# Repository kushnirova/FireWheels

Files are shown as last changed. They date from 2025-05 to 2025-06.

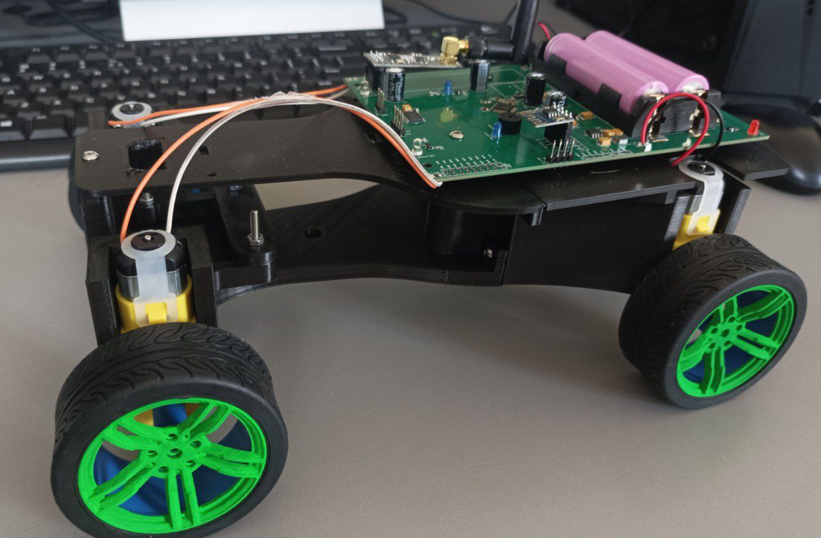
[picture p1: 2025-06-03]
photos/side2.jpg

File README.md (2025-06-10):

# 🏁 FireWheels 🏎️💨

**Projekt semestralny z przedmiotu Systemy Wbudowane i Mikroprocesory -** zdalnie sterowany robot mobilny do wyścigów i driftu

**Autorzy:** Daria Kushnirova i Mateusz Kowalczyk

**Data rozpoczęcia:** 01.05.2025

---

## ⚙️ Opis projektu

FireWheels to dynamiczny, czterokołowy robot mobilny, stworzony do szybkiej jazdy i kontrolowanych poślizgów. Napęd jest realizowany na każde z kół. Wykorzystuje układ kierowniczy Ackermanna napędzany serwomechanizmem. Komunikacja odbywa się bezprzewodowo przez Bluetooth, możliwe jest również sterowanie radiowe 2.4 GHz. Robot wyposażony jest w sygnalizacyjne diody LED oraz klakson/dodatkowy serwomechanizm. Sterowanie jest możliwe w dwóch trybach: za pomocą aplikacji mobilnej (Bluetooth) lub kontrolera bezprzewodowego (nRF). Robot został zaprogramowany za pomocą technologii FreeRTOS w STM32CubeIDE. Aplikacja mobilna napisana w Flutter (Dart) przy użyciu Android Studio.

---

## 📸 Multimedia

- **Zdjęcia:** Zobacz naszego FireWheels w akcji! [photos](https://github.com/kushnirova/FireWheels/tree/main/photos)
- **Wideo:** Nagrania z testów i prezentacji możliwości robota: [link zostanie dodany później]

---

## 🛠️ Użyte technologie i narzędzia

### Robot 🤖

- **Mikrokontroler:** STM32F103C8T6
- **IDE:** STM32CubeIDE
- **Język programowania:** C
- **Sterowanie silnikami:** Toshiba TB6612FNG x2
- **Serwomechanizm:** SG90
- **Komunikacja:** Moduł Bluetooth VG6328A/HC-04, moduł radiowy nRF24L01+PA+LNA 2.4 GHz
- **Zasilanie:** Akumulator Li-Ion 3.7V 18650 (2s)
- **Elementy dodatkowe:**
    - Diody LED
    - Buzzer / Dodatkowy serwomechanizm

### Aplikacja Mobilna 📱

- **Platforma:** Android & iOS
- **Język programowania:** Dart (Flutter)
- **Narzędzia:** Android Studio
- **Komunikacja:** Bluetooth

---

## 🛠️ Postęp prac

Postępy w poszczególnych obszarach projektu:

- **Projektowanie schematów:** [schematic_pcb](https://github.com/kushnirova/FireWheels/tree/main/schematic_pcb)
- **Projektowanie obudowy:** [3d_models](https://github.com/kushnirova/FireWheels/tree/main/3d_models)
- **Oprogramowanie robota i mikrokontrolera:** [firmware](https://github.com/kushnirova/FireWheels/tree/main/firmware/FireWheels)
- **Oprogramowanie aplikacji mobilnej:** [FireWheelsApp](https://github.com/kushnirova/FireWheels/tree/main/FireWheelsApp)

---

## 📝 Wnioski

[wnioski zostaną dopisane po ukończeniu projektu]

---

## 📧 Kontakt

Masz pytania? Skontaktuj się z nami:

- Email: [21267@student.ans-elblag.pl](mailto:21267@student.ans-elblag.pl) / [21244@student.ans-elblag.pl](mailto:21244@student.ans-elblag.pl)
- GitHub: https://github.com/kushnirova / https://github.com/kowmat

---

## 📜 Licencja

**Licencja:** MIT

---

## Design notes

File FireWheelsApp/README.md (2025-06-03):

# firewheelsapp

A new Flutter project.

## Getting Started

This project is a starting point for a Flutter application.

A few resources to get you started if this is your first Flutter project:

- [Lab: Write your first Flutter app](https://docs.flutter.dev/get-started/codelab)
- [Cookbook: Useful Flutter samples](https://docs.flutter.dev/cookbook)

For help getting started with Flutter development, view the
[online documentation](https://docs.flutter.dev/), which offers tutorials,
samples, guidance on mobile development, and a full API reference.

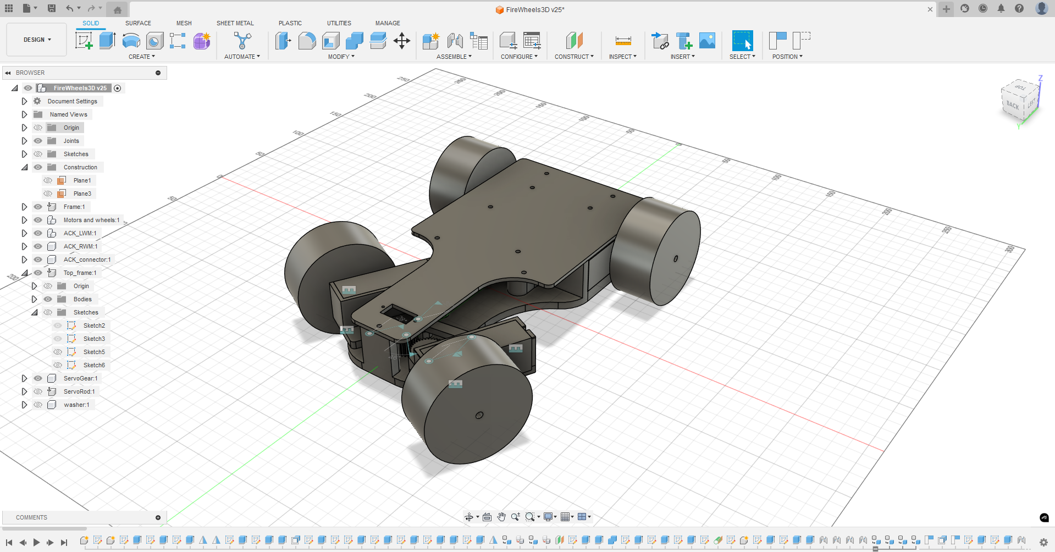
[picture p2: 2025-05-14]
3d_models/WIP_overview_1A.png

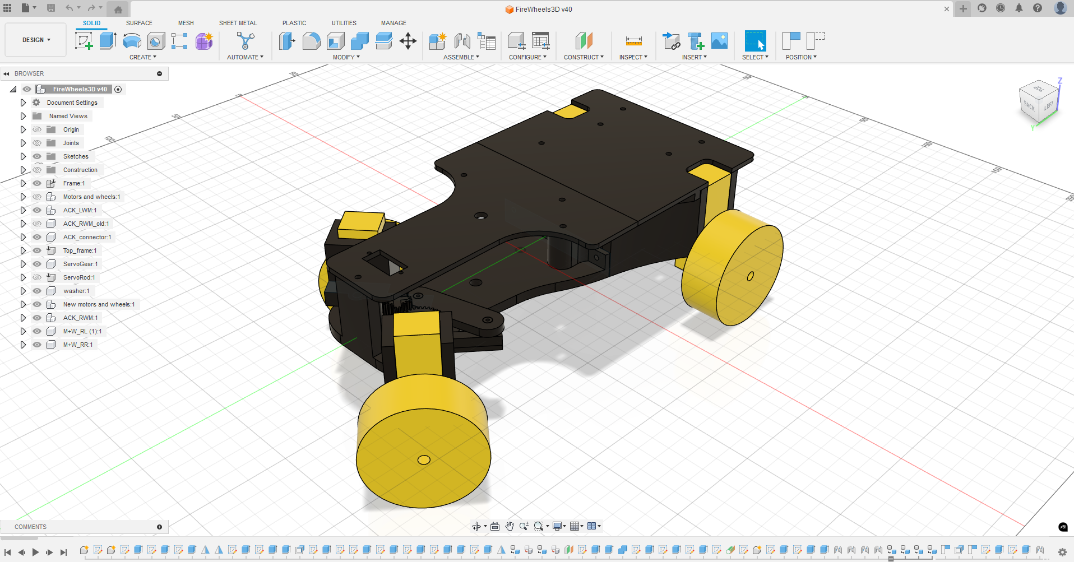
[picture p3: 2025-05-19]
3d_models/Final3D_overview_1B.png

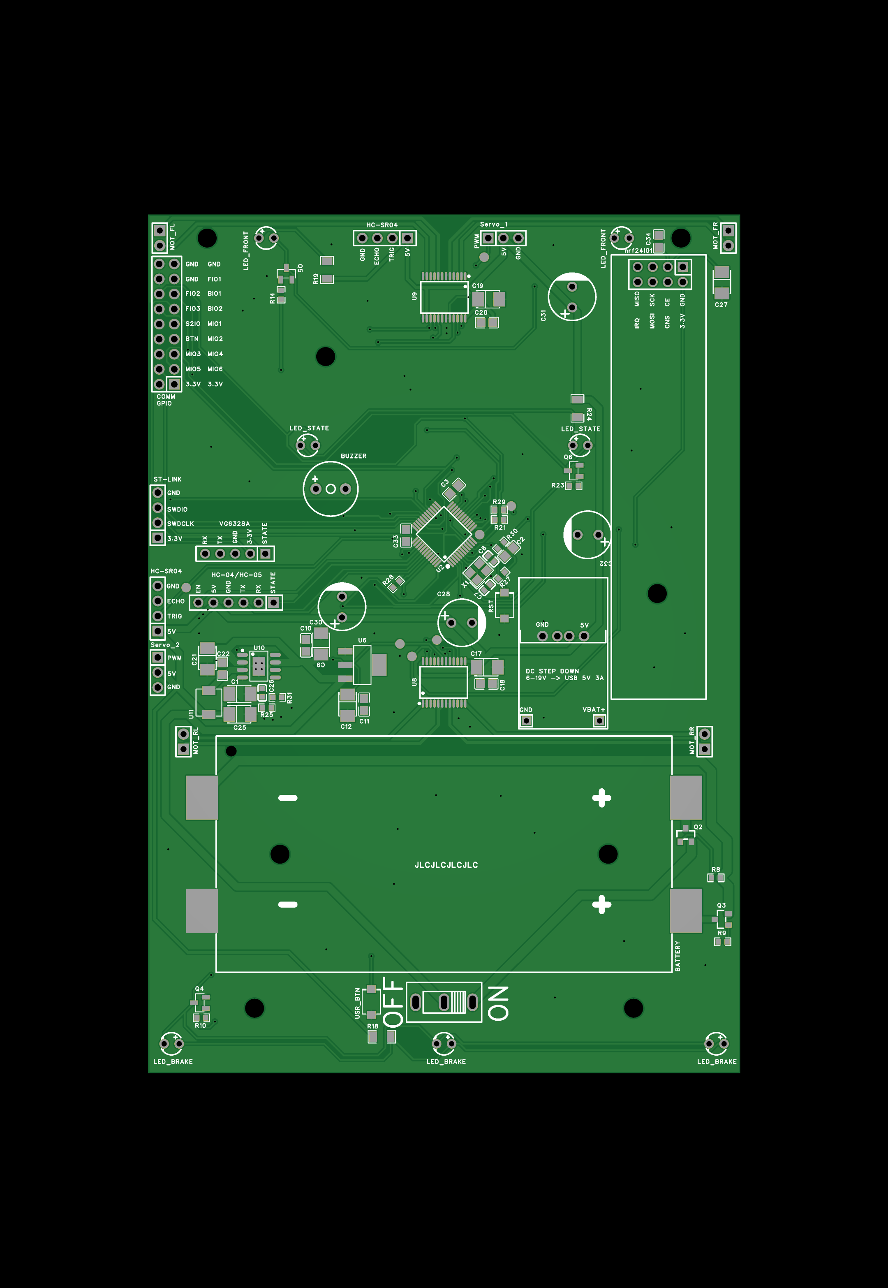
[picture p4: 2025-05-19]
schematic_pcb/PDF_PNG/PCB_MOTHERBOARD_SIDE_A.png

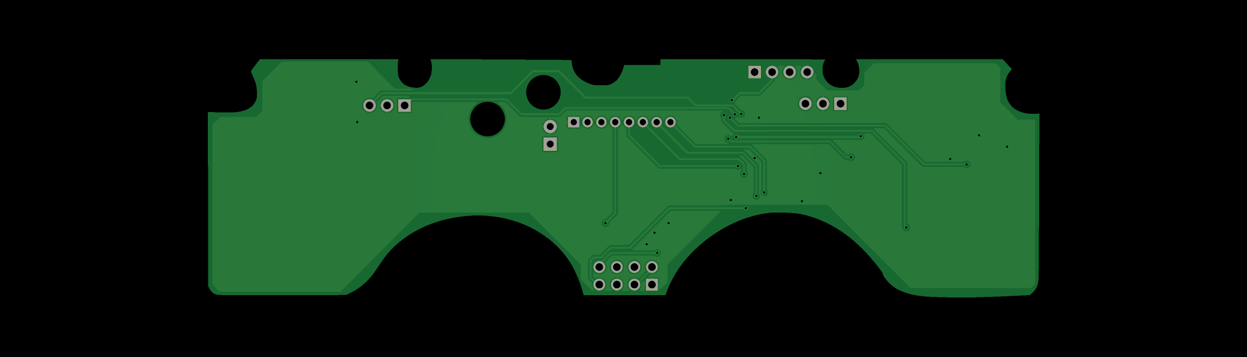
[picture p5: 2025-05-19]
schematic_pcb/PDF_PNG/PCB_RC_PAD_SIDE_B.png

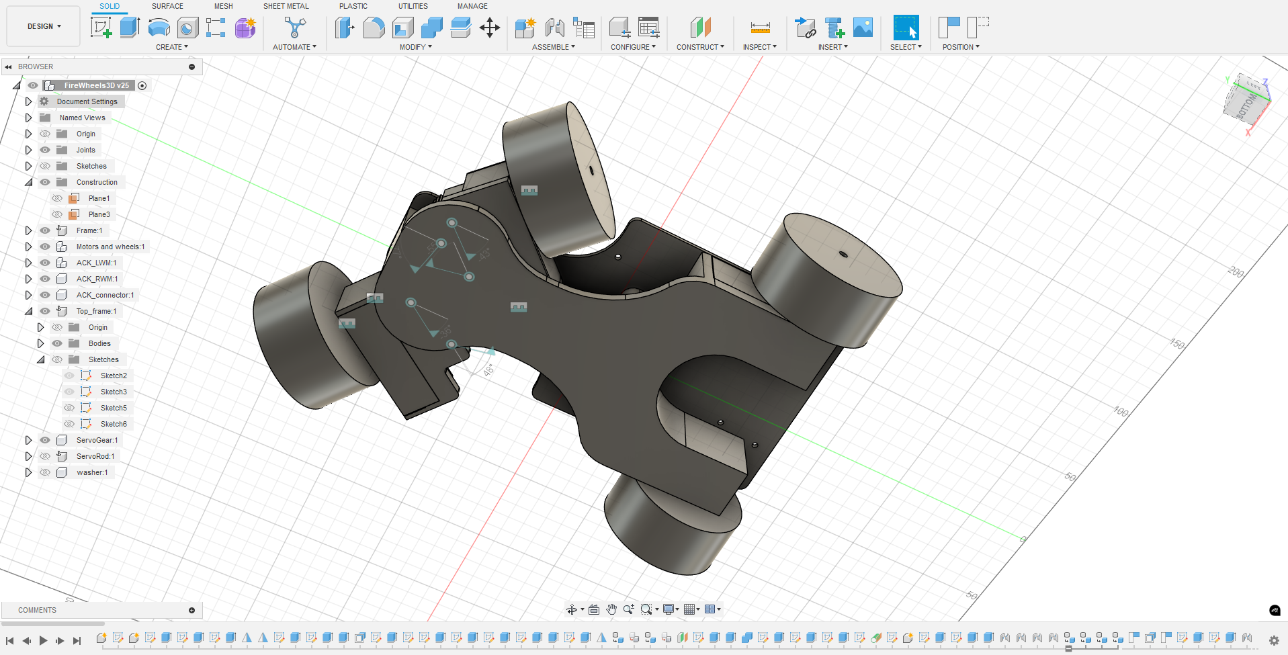
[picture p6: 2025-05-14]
3d_models/WIP_overview_1B.png

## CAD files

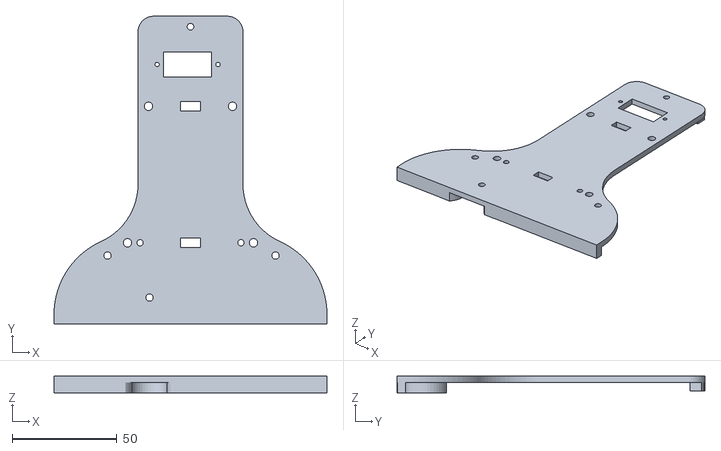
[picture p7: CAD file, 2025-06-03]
3d_models/STLs/v3/Top_frame_part2.stl
130.0 x 146.5 x 8.00

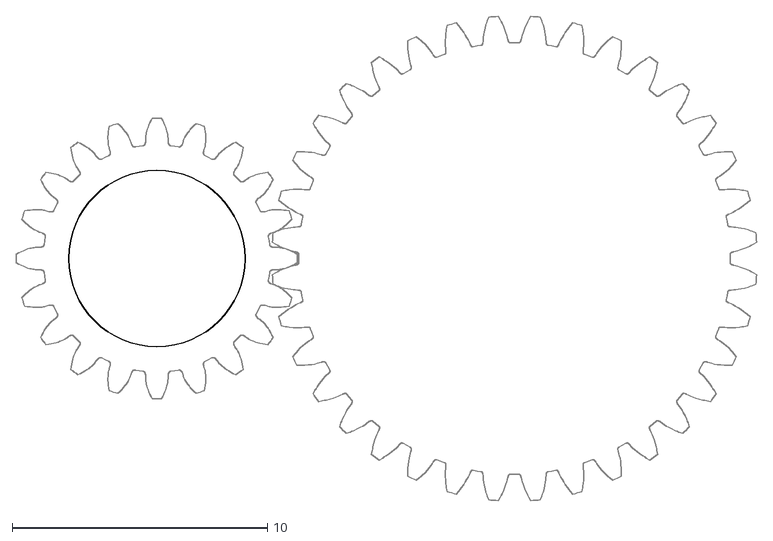
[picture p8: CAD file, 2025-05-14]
involute_gear.dxf
29.0 x 19.0

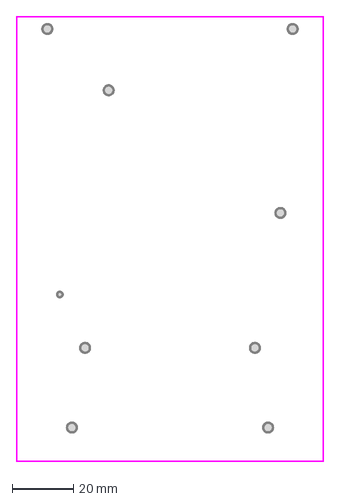
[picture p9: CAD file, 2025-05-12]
schematic_pcb/Board_outline_AutoCAD2007.dxf
100.3 x 145.3 mm

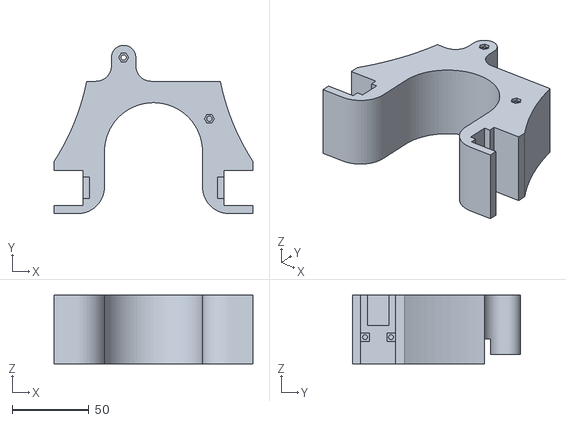
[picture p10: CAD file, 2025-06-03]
3d_models/STLs/v3/Frame_bottom_part1.stl
130.0 x 110.0 x 45.0

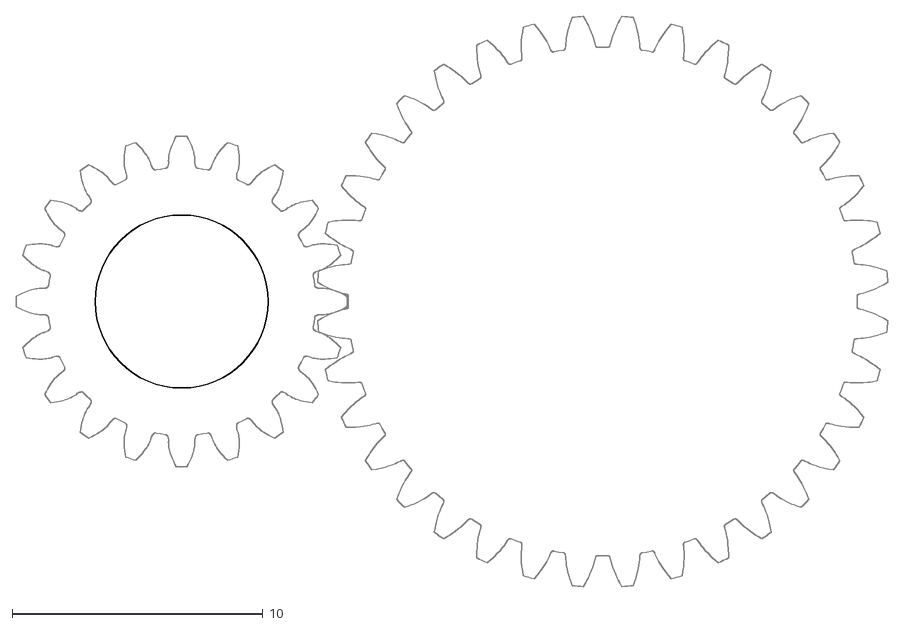
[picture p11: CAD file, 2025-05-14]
involute_gear_0_6.dxf
34.8 x 22.7

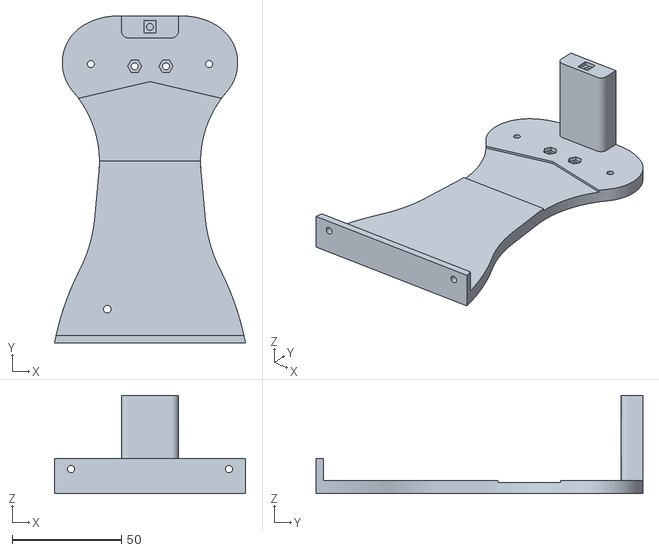
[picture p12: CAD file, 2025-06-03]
3d_models/STLs/v3/Frame_bottom_part2.stl
87.3 x 149.5 x 45.0

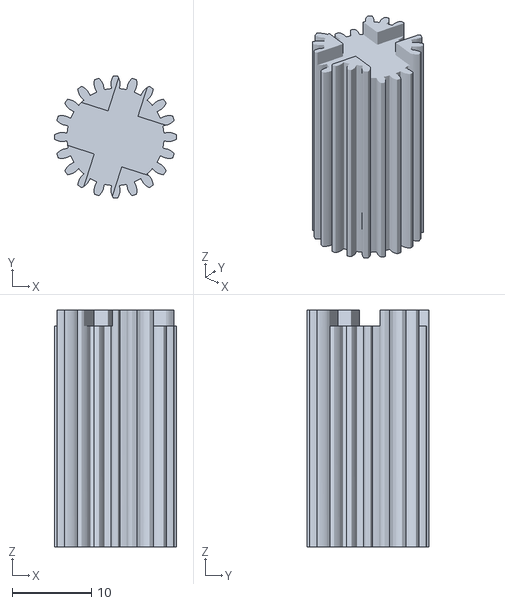
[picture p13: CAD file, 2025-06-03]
3d_models/STLs/v3/ServoGear.stl
15.4 x 15.4 x 29.9

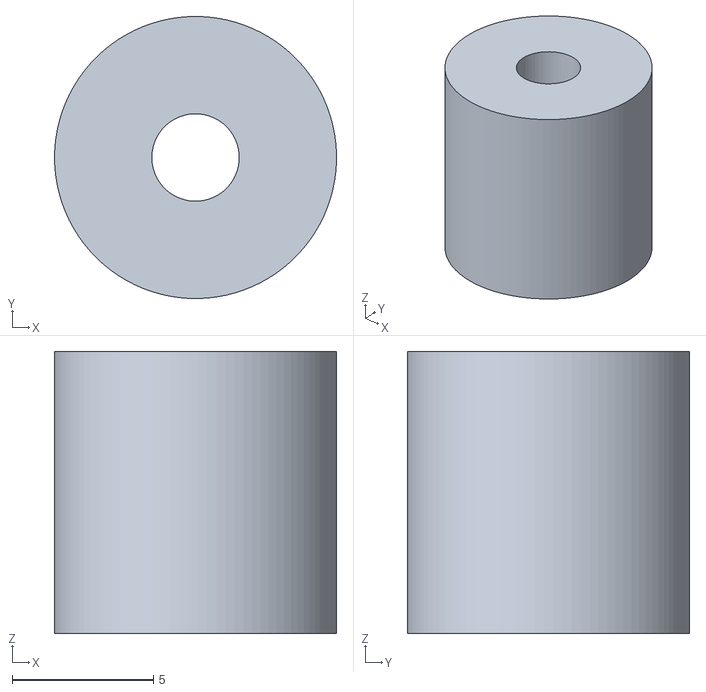
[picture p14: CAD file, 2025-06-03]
3d_models/STLs/v3/Screw_cap.stl
10.00 x 10.00 x 10.0

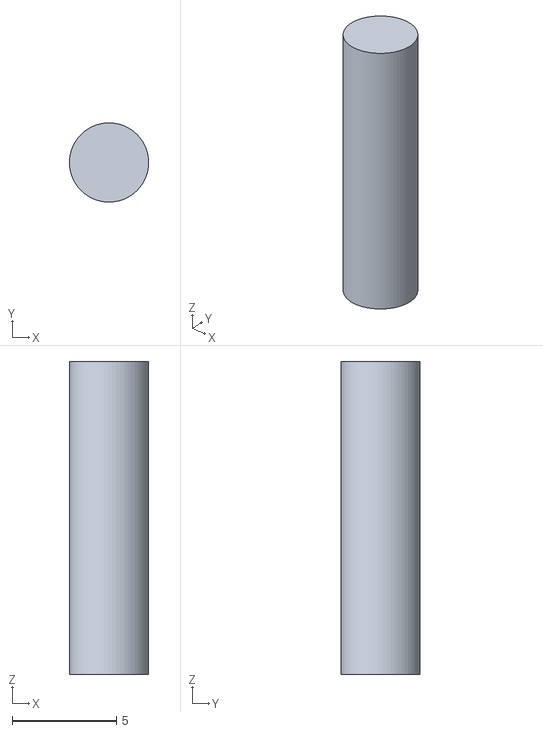
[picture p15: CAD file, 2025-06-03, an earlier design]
3d_models/STLs/v1/slupek3.stl
3.80 x 3.80 x 15.0

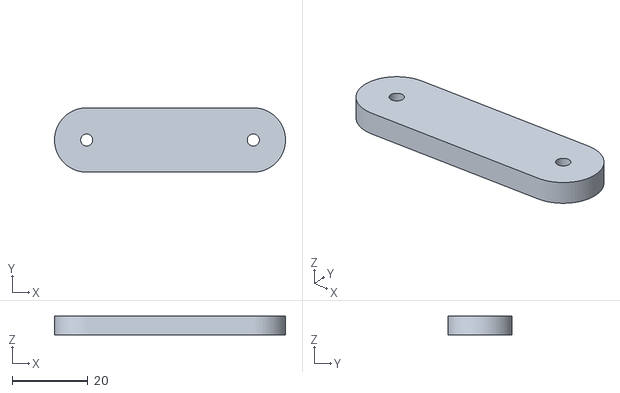
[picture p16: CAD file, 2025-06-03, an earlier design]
3d_models/STLs/v2/ACK_connector.stl
61.0 x 17.0 x 5.00

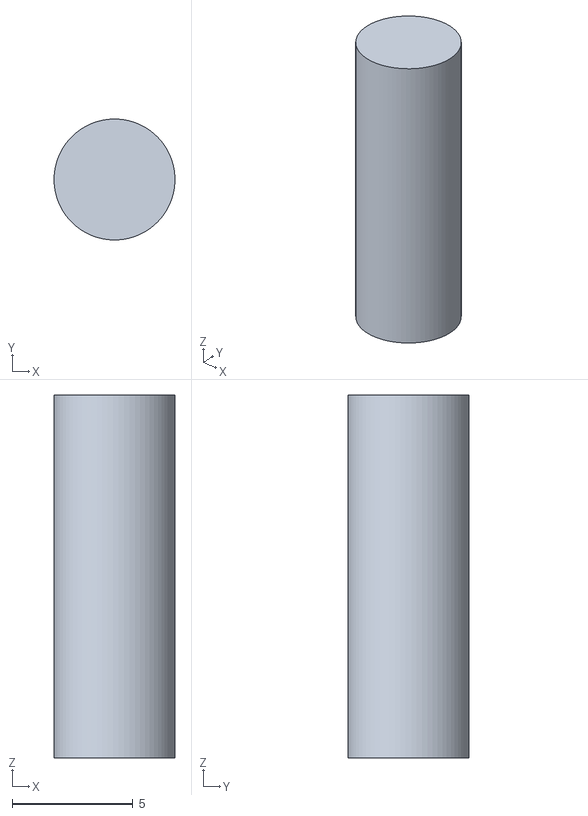
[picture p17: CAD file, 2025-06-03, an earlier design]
3d_models/STLs/v1/slupek_1.stl
5.00 x 5.00 x 15.0

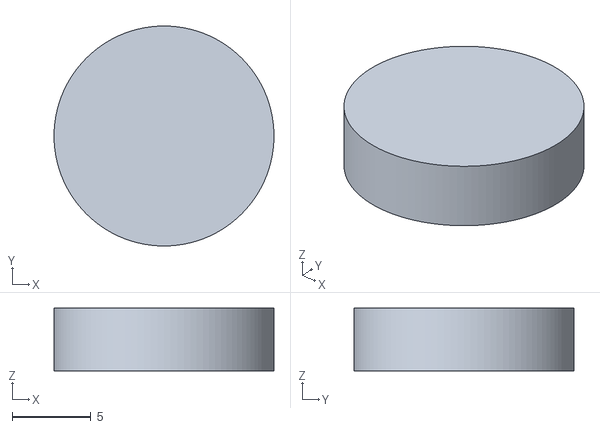
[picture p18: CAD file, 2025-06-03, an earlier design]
3d_models/STLs/v1/slupek2.stl
14.0 x 14.0 x 4.00

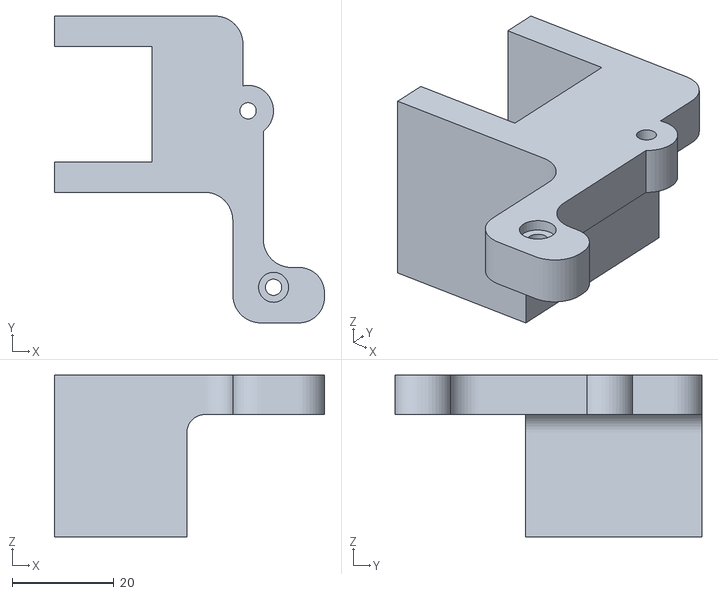
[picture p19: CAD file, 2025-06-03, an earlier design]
3d_models/STLs/v2/ACK_RWM.stl
53.0 x 60.2 x 31.7

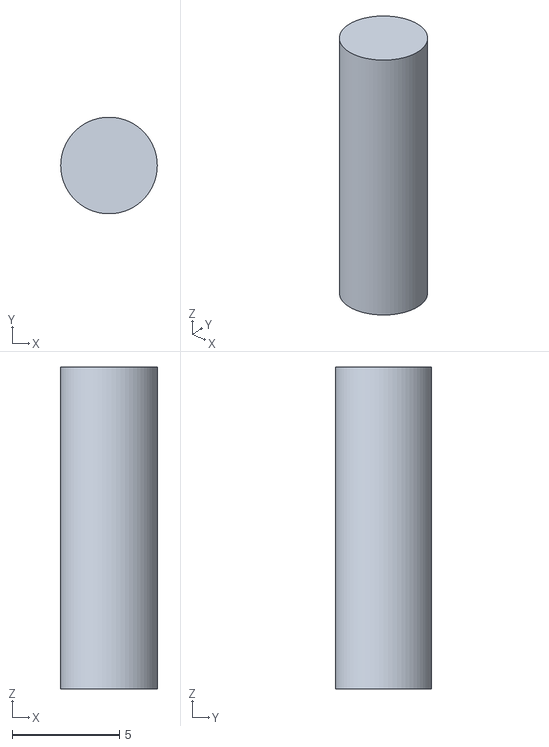
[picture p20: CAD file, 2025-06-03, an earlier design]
3d_models/STLs/v1/slupek4.stl
4.50 x 4.49 x 15.0

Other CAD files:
3d_models/STLs/v2/Top_frame_part2.stl
3d_models/STLs/v2/ACK_LWM_Combined.stl
3d_models/STLs/v1/ACK_RWM.stl
3d_models/STLs/v2/Frame_bottom_part2.stl
3d_models/STLs/v1/ACK_LWM.stl
3d_models/STLs/v1/ACK_connector.stl
3d_models/STLs/v1/Frame_bottom_part1.stl
3d_models/STLs/v1/Frame_bottom_part2.stl
3d_models/STLs/v1/ServoGear.stl
3d_models/STLs/v1/Top_frame_part2.stl
3d_models/STLs/v1/Top_frame_part_1.stl
3d_models/STLs/v1/washer.stl
3d_models/STLs/v2/PCB_distance_x8.stl

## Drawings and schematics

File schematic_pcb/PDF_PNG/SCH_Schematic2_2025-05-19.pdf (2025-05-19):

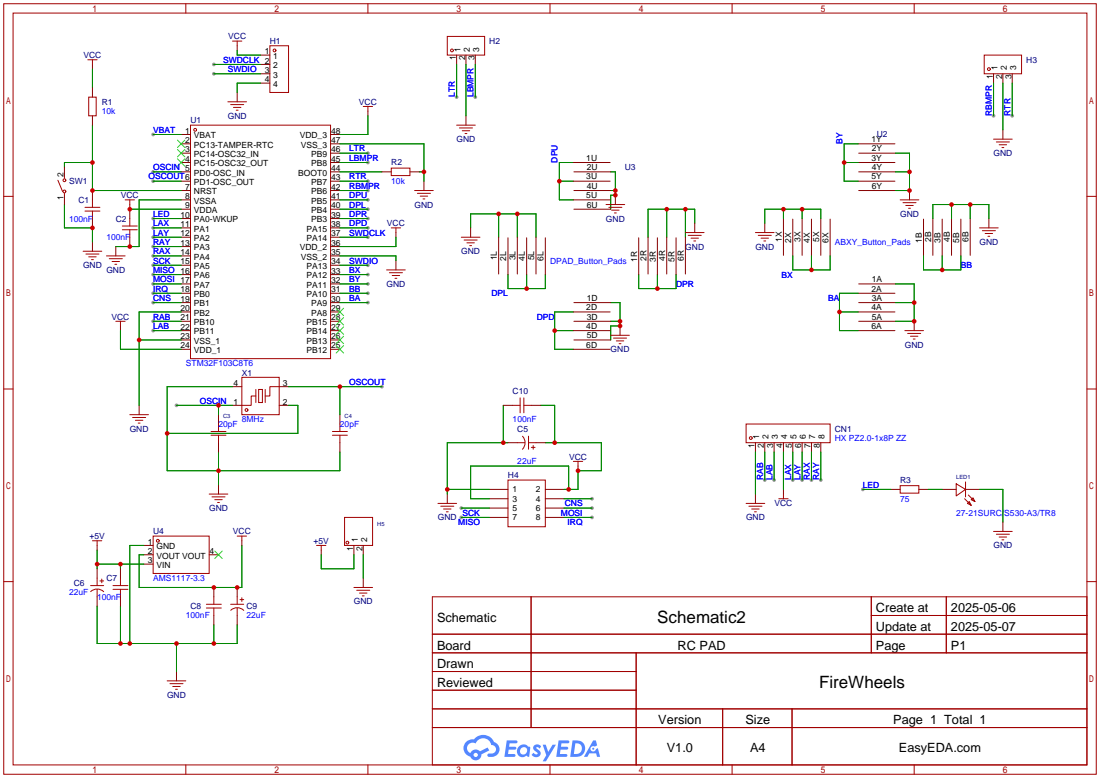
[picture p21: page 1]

Schematic | Schematic2 | Create at | 2025-05-06

Update at | 2025-05-07

Board | RC PAD | Page | P1
Drawn | | FireWheels
Reviewed

Version | Size | Page 1 Total 1
V1.0 | A4 | EasyEDA.com

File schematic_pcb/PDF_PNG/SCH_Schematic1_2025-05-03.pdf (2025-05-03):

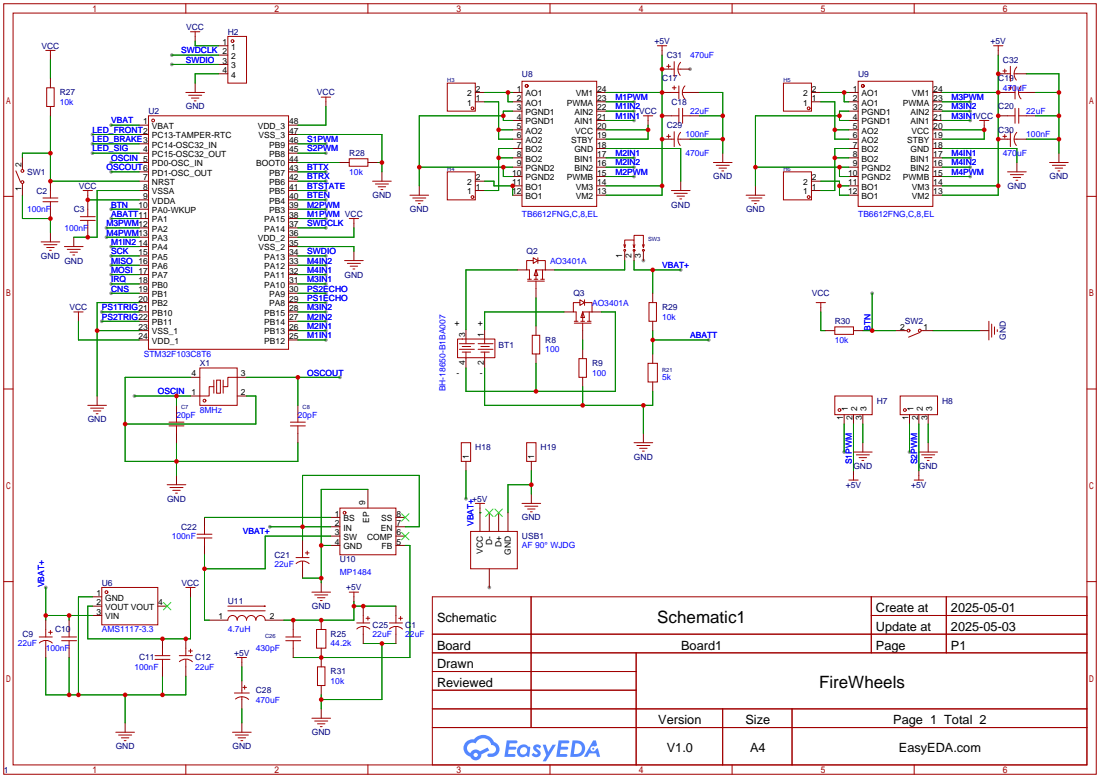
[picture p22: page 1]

Schematic | Schematic1 | Create at | 2025-05-01

Update at | 2025-05-03

Board | Board1 | Page | P1
Drawn | | FireWheels
Reviewed

Version | Size | Page 1 Total 2
V1.0 | A4 | EasyEDA.com

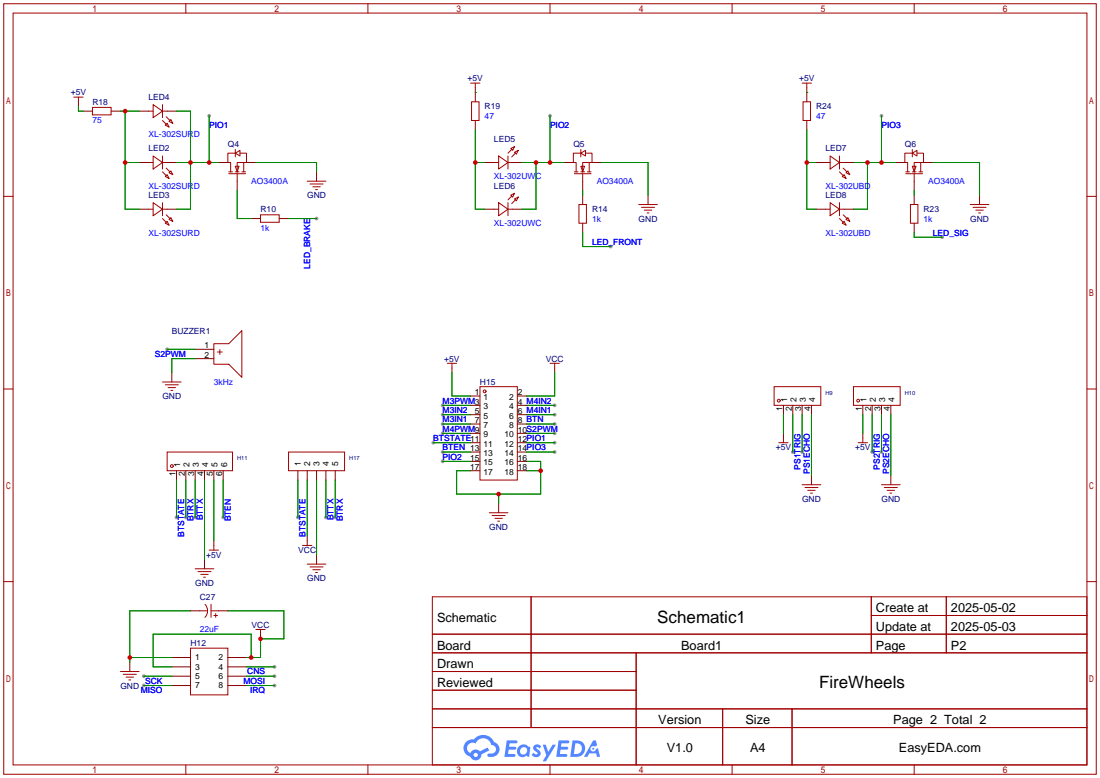
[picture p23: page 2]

Schematic | Schematic1 | Create at | 2025-05-02

Update at | 2025-05-03

Board | Board1 | Page | P2
Drawn | | FireWheels
Reviewed

Version | Size | Page 2 Total 2
V1.0 | A4 | EasyEDA.com

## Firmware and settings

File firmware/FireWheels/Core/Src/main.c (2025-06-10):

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
/* Includes ------------------------------------------------------------------*/
#include "main.h"
#include "cmsis_os.h"
#include "adc.h"
#include "spi.h"
#include "tim.h"
#include "usart.h"
#include "gpio.h"

/* USER CODE BEGIN Includes */
#include "nrf24l01p.h"
#include <stdio.h>
#include <stdlib.h>
#include <string.h>

/* USER CODE END Includes */

/* USER CODE BEGIN PTD */
typedef enum {
    CONTROL_BLUETOOTH,
    CONTROL_NRF24L01
} ControlMode_t;

typedef struct {
    int8_t left_x;    // Bajt 1
    int8_t left_y;    // Bajt 2
    int8_t right_x;   // Bajt 3
    int8_t right_y;   // Bajt 4
    uint16_t buttons; // Bajty 5-6
} ControllerData;
/* USER CODE END PTD */

/* USER CODE BEGIN PD */
#define BUZZ_GPIO_Port GPIOB
#define BUZZ_Pin GPIO_PIN_8
#define BTSTATE_GPIO_Port GPIOB
#define BTSTATE_Pin GPIO_PIN_5
#define M1IN1_GPIO_Port GPIOB
#define M1IN1_Pin GPIO_PIN_12
#define M1IN2_GPIO_Port GPIOA
#define M1IN2_Pin GPIO_PIN_4
#define M2IN2_GPIO_Port GPIOB
#define M2IN2_Pin GPIO_PIN_14
#define M3IN1_GPIO_Port GPIOA
#define M3IN1_Pin GPIO_PIN_10
#define M3IN2_GPIO_Port GPIOB
#define M3IN2_Pin GPIO_PIN_15
#define M4IN1_GPIO_Port GPIOA
#define M4IN1_Pin GPIO_PIN_11
#define M4IN2_GPIO_Port GPIOA
#define M4IN2_Pin GPIO_PIN_12
#define CNS_GPIO_Port GPIOB
#define CNS_Pin GPIO_PIN_1
#define IRQ_GPIO_Port GPIOB
#define IRQ_Pin GPIO_PIN_0
#define PS1TRIG_GPIO_Port GPIOB
#define PS1TRIG_Pin GPIO_PIN_11
#define LED_SIG_GPIO_Port GPIOC
#define LED_SIG_Pin GPIO_PIN_15
#define LED_BRAKE_GPIO_Port GPIOC
#define LED_BRAKE_Pin GPIO_PIN_14
#define LED_FRONT_GPIO_Port GPIOC
#define LED_FRONT_Pin GPIO_PIN_13
#define BTN_GPIO_Port GPIOA
#define BTN_Pin GPIO_PIN_0

#define USE_ULTRASONIC 0

#define NRF24L01P_SPI (&hspi1)
#define NRF24L01P_SPI_CS_PIN_PORT GPIOB
#define NRF24L01P_SPI_CS_PIN_NUMBER GPIO_PIN_1
#define NRF24L01P_IRQ_PIN_PORT GPIOB
#define NRF24L01P_IRQ_PIN_NUMBER GPIO_PIN_0
#define NRF24L01P_PAYLOAD_LENGTH 6

/* USER CODE END PD */


/* USER CODE BEGIN PV */
ControlMode_t currentMode = CONTROL_NRF24L01;
osMessageQueueId_t controlQueue;
uint8_t rx_byte;
uint8_t bt_rx_buffer[6];
uint8_t bt_rx_index = 0;
volatile uint32_t lastDataTime = 0; // Czas ostatniego odebranego pakietu
ControllerData controlData = {0}; // Globalna struktura przechowująca dane sterujące

#if USE_ULTRASONIC
volatile uint32_t echo_start, echo_end;
volatile uint8_t echo_flag = 0;
#endif

/* USER CODE END PV */

void SystemClock_Config(void);
void MX_FREERTOS_Init(void);
/* USER CODE BEGIN PFP */
void SystemClock_Config(void);
void MX_FREERTOS_Init(void);
void driveMotor(GPIO_TypeDef* IN1_Port, uint16_t IN1_Pin, GPIO_TypeDef* IN2_Port, uint16_t IN2_Pin, TIM_HandleTypeDef* htim, uint32_t Channel, int speed_percent);
void SG90_SetAngle(uint8_t angle);
float Battery_GetVoltage(void);
void LED_Front(uint8_t on);
void LED_Brake(uint8_t on);
void LED_Signal(uint8_t on);
uint8_t Button_IsPressed(void);
void ControlTask(void *pvParameters);
void BatteryTask(void *pvParameters);
void ButtonTask(void *pvParameters);
void StatusTask(void *pvParameters);
#if USE_ULTRASONIC
void UltrasonicTask(void *pvParameters);
#endif
/* USER CODE END PFP */

/* USER CODE BEGIN 0 */
extern TIM_HandleTypeDef htim2;
extern TIM_HandleTypeDef htim4;
extern TIM_HandleTypeDef htim1;
extern SPI_HandleTypeDef hspi1;
extern UART_HandleTypeDef huart1;
extern ADC_HandleTypeDef hadc1;

/* USER CODE END 0 */

/**
  * @brief  The application entry point.
  * @retval int
  */
int main(void)
{

  /* MCU Configuration--------------------------------------------------------*/

  /* Reset of all peripherals, Initializes the Flash interface and the Systick. */
  HAL_Init();

  /* Configure the system clock */
  SystemClock_Config();

  /* Initialize all configured peripherals */
  MX_GPIO_Init();
  MX_SPI1_Init();
  MX_TIM1_Init();
  MX_TIM2_Init();
  MX_TIM4_Init();
  MX_USART1_UART_Init();
  MX_ADC1_Init();
  /* USER CODE BEGIN 2 */
#if USE_ULTRASONIC
  MX_TIM1_Init();
#endif
  nrf24l01p_rx_init(2402, 0);

  controlQueue = osMessageQueueNew(30, sizeof(ControllerData), NULL);
    const osThreadAttr_t controlTask_attr = {
        .name = "ControlTask",
        .priority = osPriorityHigh,
        .stack_size = 1024
    };
    osThreadNew(ControlTask, NULL, &controlTask_attr);
    osThreadNew(ButtonTask, NULL, NULL);
    osThreadNew(StatusTask, NULL, NULL);
    #if USE_ULTRASONIC
      osThreadNew(UltrasonicTask, NULL, NULL);
      HAL_TIM_IC_Start_IT(&htim1, TIM_CHANNEL_1);
    #endif

    HAL_TIM_PWM_Start(&htim2, TIM_CHANNEL_1);
    HAL_TIM_PWM_Start(&htim2, TIM_CHANNEL_2);
    HAL_TIM_PWM_Start(&htim2, TIM_CHANNEL_3);
    HAL_TIM_PWM_Start(&htim2, TIM_CHANNEL_4);
    HAL_TIM_PWM_Start(&htim4, TIM_CHANNEL_4);

    driveMotor(M1IN1_GPIO_Port, M1IN1_Pin, M1IN2_GPIO_Port, M1IN2_Pin, &htim2, TIM_CHANNEL_1, 0);
    driveMotor(M2IN1_GPIO_Port, M2IN1_Pin, M2IN2_GPIO_Port, M2IN2_Pin, &htim2, TIM_CHANNEL_2, 0);
    driveMotor(M3IN1_GPIO_Port, M3IN1_Pin, M3IN2_GPIO_Port, M3IN2_Pin, &htim2, TIM_CHANNEL_3, 0);
    driveMotor(M4IN1_GPIO_Port, M4IN1_Pin, M4IN2_GPIO_Port, M4IN2_Pin, &htim2, TIM_CHANNEL_4, 0);
    SG90_SetAngle(90);
  /* USER CODE END 2 */

  /* Init scheduler */
  osKernelInitialize();

  /* Call init function for freertos objects (in cmsis_os2.c) */
  MX_FREERTOS_Init();

  /* Start scheduler */
  osKernelStart();

  /* We should never get here as control is now taken by the scheduler */

  /* Infinite loop */
  /* USER CODE BEGIN WHILE */
  while (1)
  {
    /* USER CODE END WHILE */

    /* USER CODE BEGIN 3 */
  }
  /* USER CODE END 3 */
}

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
/* USER CODE BEGIN 4 */
void ControlTask(void *pvParameters) {
    ControllerData data;
    while (1) {
         //Sprawdź, czy minęło 100 ms od ostatniego pakietu
        if (HAL_GetTick() - lastDataTime > 100) {
            // Zeruj controlData i zatrzymaj silniki
            controlData.left_x = 0;
            controlData.left_y = 0;
            controlData.right_x = 0;
            controlData.right_y = 0;
            controlData.buttons = 0;
            SG90_SetAngle(90); // Ustaw serwo na pozycję neutralną
            driveMotor(M1IN1_GPIO_Port, M1IN1_Pin, M1IN2_GPIO_Port, M1IN2_Pin, &htim2, TIM_CHANNEL_1, 0);
            driveMotor(M2IN1_GPIO_Port, M2IN1_Pin, M2IN2_GPIO_Port, M2IN2_Pin, &htim2, TIM_CHANNEL_2, 0);
            driveMotor(M3IN1_GPIO_Port, M3IN1_Pin, M3IN2_GPIO_Port, M3IN2_Pin, &htim2, TIM_CHANNEL_3, 0);
            driveMotor(M4IN1_GPIO_Port, M4IN1_Pin, M4IN2_GPIO_Port, M4IN2_Pin, &htim2, TIM_CHANNEL_4, 0);
            LED_Brake(1); // Włącz światła stopu
            LED_Front(0); // Wyłącz światła przednie
            HAL_GPIO_WritePin(BUZZ_GPIO_Port, BUZZ_Pin, GPIO_PIN_RESET); // Wyłącz buzzer
        }

        // Czekaj na nowy pakiet z kolejki
        if (osMessageQueueGet(controlQueue, &data, NULL, 0) == osOK) {
        	if(currentMode == CONTROL_NRF24L01){
        		controlData = data;
				lastDataTime = HAL_GetTick();

				// Sterowanie robotem
				int speed = controlData.left_y;
				int angle = (controlData.right_x + 100) * 180 / 200;

				SG90_SetAngle((uint8_t)angle);
				driveMotor(M1IN1_GPIO_Port, M1IN1_Pin, M1IN2_GPIO_Port, M1IN2_Pin, &htim2, TIM_CHANNEL_1, speed * -1);
				driveMotor(M2IN1_GPIO_Port, M2IN1_Pin, M2IN2_GPIO_Port, M2IN2_Pin, &htim2, TIM_CHANNEL_2, speed * -1);
				driveMotor(M3IN1_GPIO_Port, M3IN1_Pin, M3IN2_GPIO_Port, M3IN2_Pin, &htim2, TIM_CHANNEL_3, speed);
				driveMotor(M4IN1_GPIO_Port, M4IN1_Pin, M4IN2_GPIO_Port, M4IN2_Pin, &htim2, TIM_CHANNEL_4, speed);

				LED_Brake(speed <= 0 ? 1 : 0);
				LED_Front(controlData.buttons & 0x01 ? 1 : 0);
				HAL_GPIO_WritePin(BUZZ_GPIO_Port, BUZZ_Pin, (controlData.buttons & 0x02) ? GPIO_PIN_SET : GPIO_PIN_RESET);
        	}
        	else{
        		controlData = data;
				lastDataTime = HAL_GetTick();

				// Sterowanie robotem
				int speed = controlData.left_x;
				int angle = (controlData.left_y + 100) * 180 / 200;

				SG90_SetAngle((uint8_t)angle);
				driveMotor(M1IN1_GPIO_Port, M1IN1_Pin, M1IN2_GPIO_Port, M1IN2_Pin, &htim2, TIM_CHANNEL_1, speed * -1);
				driveMotor(M2IN1_GPIO_Port, M2IN1_Pin, M2IN2_GPIO_Port, M2IN2_Pin, &htim2, TIM_CHANNEL_2, speed * -1);
				driveMotor(M3IN1_GPIO_Port, M3IN1_Pin, M3IN2_GPIO_Port, M3IN2_Pin, &htim2, TIM_CHANNEL_3, speed);
				driveMotor(M4IN1_GPIO_Port, M4IN1_Pin, M4IN2_GPIO_Port, M4IN2_Pin, &htim2, TIM_CHANNEL_4, speed);

				LED_Brake(speed <= 0 ? 1 : 0);
				LED_Front(controlData.buttons & 0x01 ? 1 : 0);
				HAL_GPIO_WritePin(BUZZ_GPIO_Port, BUZZ_Pin, (controlData.buttons & 0x02) ? GPIO_PIN_SET : GPIO_PIN_RESET);
        	}


            // Aktualizuj controlData

        }

        osDelay(10); // Krótkie opóźnienie, aby nie obciążać procesora
    }
}

void sendCommand(const char* cmd)
{
  HAL_UART_Transmit(&huart1, (uint8_t*)cmd, strlen(cmd), HAL_MAX_DELAY);
}

void BatteryTask(void *pvParameters) {
    while (1) {
        float voltage = Battery_GetVoltage();
        if (voltage < 2.0f) {
            for (int i = 0; i < 3; i++) {
                HAL_GPIO_WritePin(BUZZ_GPIO_Port, BUZZ_Pin, GPIO_PIN_SET);
                osDelay(100);
                HAL_GPIO_WritePin(BUZZ_GPIO_Port, BUZZ_Pin, GPIO_PIN_RESET);
                osDelay(100);
            }
        }
        osDelay(5000);
    }
}

void ButtonTask(void *pvParameters) {
    while (1) {
        if (Button_IsPressed()) {
            osDelay(20);
            if (Button_IsPressed()) {
                if (currentMode == CONTROL_BLUETOOTH) {
                    currentMode = CONTROL_NRF24L01;
                    HAL_NVIC_EnableIRQ(EXTI0_IRQn);
                    HAL_UART_AbortReceive_IT(&huart1);
                } else {
                    currentMode = CONTROL_BLUETOOTH;
                    HAL_NVIC_DisableIRQ(EXTI0_IRQn);
                    HAL_UART_Receive_IT(&huart1, &rx_byte, 1);
                }
                HAL_GPIO_WritePin(BUZZ_GPIO_Port, BUZZ_Pin, GPIO_PIN_SET);
                osDelay(200);
                HAL_GPIO_WritePin(BUZZ_GPIO_Port, BUZZ_Pin, GPIO_PIN_RESET);
            }
        }
        osDelay(10);
    }
}

void StatusTask(void *pvParameters) {
    while (1) {
        if (currentMode == CONTROL_BLUETOOTH) {
            LED_Signal(1);
            osDelay(500);
            LED_Signal(0);
            osDelay(500);
        } else if (currentMode == CONTROL_NRF24L01) {
            LED_Signal(1);
            osDelay(1000);
        }
        osDelay(10);
    }
}

#if USE_ULTRASONIC
void UltrasonicTask(void *pvParameters) {
    while (1) {
        HAL_GPIO_WritePin(PS1TRIG_GPIO_Port, PS1TRIG_Pin, GPIO_PIN_SET);
        HAL_Delay(1);
        HAL_GPIO_WritePin(PS1TRIG_GPIO_Port, PS1TRIG_Pin, GPIO_PIN_RESET);

        echo_flag = 0;
        while (!echo_flag) {
            osDelay(10);
        }

        uint32_t time_us = echo_end - echo_start;
        float distance = time_us / 58.0f;

        if (distance < 20.0f) {
            // Możesz dodać akcję, np. zatrzymanie pojazdu
        }

        osDelay(100);
    }
}

void HAL_TIM_IC_CaptureCallback(TIM_HandleTypeDef *htim) {
    if (htim == &htim1 && htim->Channel == HAL_TIM_ACTIVE_CHANNEL_1) {
        if (HAL_GPIO_ReadPin(GPIOA, GPIO_PIN_8) == GPIO_PIN_SET) {
            echo_start = HAL_TIM_ReadCapturedValue(htim, TIM_CHANNEL_1);
        } else {
            echo_end = HAL_TIM_ReadCapturedValue(htim, TIM_CHANNEL_1);
            echo_flag = 1;
        }
    }
}
#endif

void HAL_GPIO_EXTI_Callback(uint16_t GPIO_Pin) {
    if (GPIO_Pin == IRQ_Pin && currentMode == CONTROL_NRF24L01) {
        ControllerData data;
        nrf24l01p_rx_receive((uint8_t*)&data);

        if (osMessageQueueGetSpace(controlQueue) == 0) {
            ControllerData dummy;
            osMessageQueueGet(controlQueue, &dummy, NULL, 0);
        }

        lastDataTime = HAL_GetTick();
        osMessageQueuePut(controlQueue, &data, 0, 0);
    }
}

void HAL_UART_RxCpltCallback(UART_HandleTypeDef *huart) {
    if (huart == &huart1 && currentMode == CONTROL_BLUETOOTH) {
        bt_rx_buffer[bt_rx_index++] = rx_byte;
        if (bt_rx_index >= 6) {
            ControllerData data;
            memcpy(&data, bt_rx_buffer, 6);
            lastDataTime = HAL_GetTick();
            osMessageQueuePut(controlQueue, &data, 0, 0);
            bt_rx_index = 0;
        }
        if(HAL_UART_Receive_IT(&huart1, &rx_byte, 1) == HAL_OK){
        	LED_Front(1);
        }
        else{
        	LED_Brake(1);
        };
    }
}

void driveMotor(GPIO_TypeDef* IN1_Port, uint16_t IN1_Pin, GPIO_TypeDef* IN2_Port, uint16_t IN2_Pin, TIM_HandleTypeDef* htim, uint32_t Channel, int speed_percent) {
    if (speed_percent > 0) {
        HAL_GPIO_WritePin(IN1_Port, IN1_Pin, GPIO_PIN_SET);
        HAL_GPIO_WritePin(IN2_Port, IN2_Pin, GPIO_PIN_RESET);
    } else if (speed_percent < 0) {
        HAL_GPIO_WritePin(IN1_Port, IN1_Pin, GPIO_PIN_RESET);
        HAL_GPIO_WritePin(IN2_Port, IN2_Pin, GPIO_PIN_SET);
    } else {
        HAL_GPIO_WritePin(IN1_Port, IN1_Pin, GPIO_PIN_RESET);
        HAL_GPIO_WritePin(IN2_Port, IN2_Pin, GPIO_PIN_RESET);
    }
    if (speed_percent > 100) {
        speed_percent = 100;
    }
    if (speed_percent < -100) {
        speed_percent = -100;
    }
    __HAL_TIM_SET_COMPARE(htim, Channel, abs(speed_percent));
}

void SG90_SetAngle(uint8_t angle) {
    uint32_t ccr_value = 500 + (angle * 2000 / 180);
    __HAL_TIM_SET_COMPARE(&htim4, TIM_CHANNEL_4, ccr_value);
}

float Battery_GetVoltage(void) {
    HAL_ADC_Start(&hadc1);
    HAL_ADC_PollForConversion(&hadc1, 10);
    uint32_t raw = HAL_ADC_GetValue(&hadc1);
    return ((float)raw / 4095.0f) * 3.3f * 3;
}

void LED_Front(uint8_t on) {
    HAL_GPIO_WritePin(LED_FRONT_GPIO_Port, LED_FRONT_Pin, on ? GPIO_PIN_SET : GPIO_PIN_RESET);
}

void LED_Brake(uint8_t on) {
    HAL_GPIO_WritePin(LED_BRAKE_GPIO_Port, LED_BRAKE_Pin, on ? GPIO_PIN_SET : GPIO_PIN_RESET);
}

void LED_Signal(uint8_t on) {
    HAL_GPIO_WritePin(LED_SIG_GPIO_Port, LED_SIG_Pin, on ? GPIO_PIN_SET : GPIO_PIN_RESET);
}

uint8_t Button_IsPressed(void) {
    return HAL_GPIO_ReadPin(BTN_GPIO_Port, BTN_Pin) == GPIO_PIN_RESET;
}
/* USER CODE END 4 */

/**
  * @brief  Period elapsed callback in non blocking mode
  * @note   This function is called  when TIM3 interrupt took place, inside
  * HAL_TIM_IRQHandler(). It makes a direct call to HAL_IncTick() to increment
  * a global variable "uwTick" used as application time base.
  * @param  htim : TIM handle
  * @retval None
  */
void HAL_TIM_PeriodElapsedCallback(TIM_HandleTypeDef *htim)
{
  if (htim->Instance == TIM3)
  {
    HAL_IncTick();
  }
}

/**
  * @brief  This function is executed in case of error occurrence.
  * @retval None
  */
void Error_Handler(void)
{
  /* USER CODE BEGIN Error_Handler_Debug */
  /* User can add his own implementation to report the HAL error return state */
  __disable_irq();
  while (1)
  {
  }
  /* USER CODE END Error_Handler_Debug */
}

#ifdef  USE_FULL_ASSERT
/**
  * @brief  Reports the name of the source file and the source line number
  *         where the assert_param error has occurred.
  * @param  file: pointer to the source file name
  * @param  line: assert_param error line source number
  * @retval None
  */
void assert_failed(uint8_t *file, uint32_t line)
{
  /* USER CODE BEGIN 6 */
  /* User can add his own implementation to report the file name and line number,
     ex: printf("Wrong parameters value: file %s on line %d\r\n", file, line) */
  /* USER CODE END 6 */
}
#endif /* USE_FULL_ASSERT */

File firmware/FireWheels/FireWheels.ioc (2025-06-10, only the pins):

Mcu.UserName=STM32F103C8Tx
PA0-WKUP.GPIO_Label=BTN
PA0-WKUP.Signal=GPIO_Input
PA1.GPIO_Label=BATT
PA1.Signal=ADCx_IN1
PA10.GPIO_Label=M3IN1
PA10.Signal=GPIO_Output
PA11.GPIO_Label=M4IN1
PA11.Signal=GPIO_Output
PA12.GPIO_Label=M4IN2
PA12.Signal=GPIO_Output
PA13.Signal=SYS_JTMS-SWDIO
PA14.Signal=SYS_JTCK-SWCLK
PA15.GPIO_Label=M1PWM
PA15.Signal=S_TIM2_CH1_ETR
PA2.GPIO_Label=M3PWM
PA2.Signal=S_TIM2_CH3
PA3.GPIO_Label=M4PWM
PA3.Signal=S_TIM2_CH4
PA4.GPIO_Label=M1IN2
PA4.Signal=GPIO_Output
PA5.Signal=SPI1_SCK
PA6.Signal=SPI1_MISO
PA7.Signal=SPI1_MOSI
PA8.GPIO_Label=PS1ECHO
PA8.Signal=S_TIM1_CH1
PA9.GPIO_Label=PS2ECHO
PA9.Signal=S_TIM1_CH2
PB0.GPIO_Label=IRQ
PB0.Signal=GPXTI0
PB1.GPIO_Label=CNS
PB1.Signal=GPIO_Output
PB10.GPIO_Label=PS1TRIG
PB10.Signal=GPIO_Output
PB11.GPIO_Label=PS2TRIG
PB11.Signal=GPIO_Output
PB12.GPIO_Label=M1IN1
PB12.Signal=GPIO_Output
PB13.GPIO_Label=M2IN1
PB13.Signal=GPIO_Output
PB14.GPIO_Label=M2IN2
PB14.Signal=GPIO_Output
PB15.GPIO_Label=M3IN2
PB15.Signal=GPIO_Output
PB3.GPIO_Label=M2PWM
PB3.Signal=S_TIM2_CH2
PB4.GPIO_Label=BTEN
PB4.Signal=GPIO_Output
PB5.GPIO_Label=BTSTATE
PB5.Signal=GPIO_Output
PB6.Signal=USART1_TX
PB7.Signal=USART1_RX
PB8.GPIO_Label=BUZZ
PB8.Signal=GPIO_Output
PB9.GPIO_Label=S1PWM
PB9.Signal=S_TIM4_CH4
PC13-TAMPER-RTC.GPIO_Label=LED_FRONT
PC13-TAMPER-RTC.Signal=GPIO_Output
PC14-OSC32_IN.GPIO_Label=LED_BRAKE
PC14-OSC32_IN.Signal=GPIO_Output
PC15-OSC32_OUT.GPIO_Label=LED_SIG
PC15-OSC32_OUT.Signal=GPIO_Output
PD0-OSC_IN.Signal=RCC_OSC_IN
PD1-OSC_OUT.Signal=RCC_OSC_OUT

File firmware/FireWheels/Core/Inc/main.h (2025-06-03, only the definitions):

#define LED_FRONT_Pin GPIO_PIN_13
#define LED_FRONT_GPIO_Port GPIOC
#define LED_BRAKE_Pin GPIO_PIN_14
#define LED_BRAKE_GPIO_Port GPIOC
#define LED_SIG_Pin GPIO_PIN_15
#define LED_SIG_GPIO_Port GPIOC
#define BTN_Pin GPIO_PIN_0
#define BTN_GPIO_Port GPIOA
#define BATT_Pin GPIO_PIN_1
#define BATT_GPIO_Port GPIOA
#define M3PWM_Pin GPIO_PIN_2
#define M3PWM_GPIO_Port GPIOA
#define M4PWM_Pin GPIO_PIN_3
#define M4PWM_GPIO_Port GPIOA
#define M1IN2_Pin GPIO_PIN_4
#define M1IN2_GPIO_Port GPIOA
#define IRQ_Pin GPIO_PIN_0
#define IRQ_GPIO_Port GPIOB
#define IRQ_EXTI_IRQn EXTI0_IRQn
#define CNS_Pin GPIO_PIN_1
#define CNS_GPIO_Port GPIOB
#define PS1TRIG_Pin GPIO_PIN_10
#define PS1TRIG_GPIO_Port GPIOB
#define PS2TRIG_Pin GPIO_PIN_11
#define PS2TRIG_GPIO_Port GPIOB
#define M1IN1_Pin GPIO_PIN_12
#define M1IN1_GPIO_Port GPIOB
#define M2IN1_Pin GPIO_PIN_13
#define M2IN1_GPIO_Port GPIOB
#define M2IN2_Pin GPIO_PIN_14
#define M2IN2_GPIO_Port GPIOB
#define M3IN2_Pin GPIO_PIN_15
#define M3IN2_GPIO_Port GPIOB
#define PS1ECHO_Pin GPIO_PIN_8
#define PS1ECHO_GPIO_Port GPIOA
#define PS2ECHO_Pin GPIO_PIN_9
#define PS2ECHO_GPIO_Port GPIOA
#define M3IN1_Pin GPIO_PIN_10
#define M3IN1_GPIO_Port GPIOA
#define M4IN1_Pin GPIO_PIN_11
#define M4IN1_GPIO_Port GPIOA
#define M4IN2_Pin GPIO_PIN_12
#define M4IN2_GPIO_Port GPIOA
#define M1PWM_Pin GPIO_PIN_15
#define M1PWM_GPIO_Port GPIOA
#define M2PWM_Pin GPIO_PIN_3
#define M2PWM_GPIO_Port GPIOB
#define BTEN_Pin GPIO_PIN_4
#define BTEN_GPIO_Port GPIOB
#define BTSTATE_Pin GPIO_PIN_5
#define BTSTATE_GPIO_Port GPIOB
#define BUZZ_Pin GPIO_PIN_8
#define BUZZ_GPIO_Port GPIOB
#define S1PWM_Pin GPIO_PIN_9
#define S1PWM_GPIO_Port GPIOB

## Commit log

2025-05-03 Zaprojektowano PCB, ulepszono schemat
2025-05-12 Dodano projekt PCB kontrolera 2.4GHz, ulepszenia
2025-05-12 Poprawki PCB
2025-05-12 Rozpoczeto modelowanie 3D - podglad png
    [Board_outline_AutoCAD2007.dxf]
2025-05-14 Poprawki modelu 3D, usprawnienie mechanizmu skretu
    [involute_gear.dxf, involute_gear_0_6.dxf]
2025-05-19 Dodano finalne modele 3D, zaktualizowano PCB
    [ACK_LWM.stl, ACK_RWM.stl, ACK_connector.stl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]
2025-05-19 Dodano firmware z projektem STM32CubeIDE dla FWMB
2025-05-27 Add files via upload
    Zdjęcia gotowych płytek PCB i robota
2025-06-03 Dodano firmware dla maiborad oraz RC - z nrf24l01
    [ACK_LWM.stl, ACK_LWM_Combined.stl, ACK_RWM.stl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]

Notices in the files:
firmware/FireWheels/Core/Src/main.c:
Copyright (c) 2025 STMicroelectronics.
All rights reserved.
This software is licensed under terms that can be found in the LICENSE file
